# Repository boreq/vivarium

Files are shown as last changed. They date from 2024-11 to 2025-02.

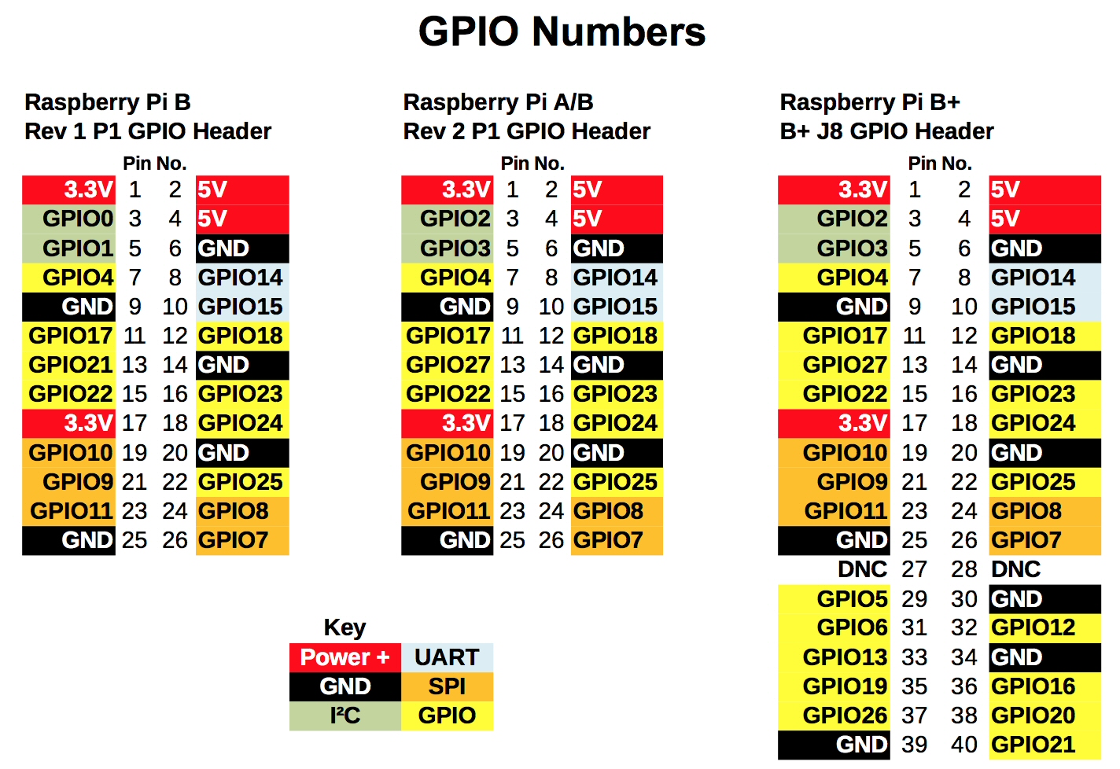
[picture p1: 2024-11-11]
automation/pins.jpg

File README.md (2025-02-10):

# Vivarium

Automation and designs for my vivarium. This readme was written as a desperate
attempt at helping future me when something inevitably breaks at the worst
possible moment.

## Vivarium

### Plants

- [*Pellaea rotundifolia*](https://duckduckgo.com/?q=Pellaea+rotundifolia&iar=images&iax=images&ia=images)
- [*Hemionitis arifolia*](https://duckduckgo.com/?q=Hemionitis+arifolia&iax=images&ia=images)
- [*Nephrolepis cordifolia* ‘Duffii’](https://duckduckgo.com/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)
- [*Pyrrosia nummularifolia*](https://duckduckgo.com/?q=Pyrrosia+nummularifolia&iax=images&ia=images)
- [*Phymatosorus diversifolius*](https://duckduckgo.com/?q=Phymatosorus+diversifolius&iar=images&iax=images&ia=images)
- [*Microgramma nitida*](https://duckduckgo.com/?q=Microgramma+nitida&iar=images&iax=images&ia=images)
- [*Pleurozium schreberi*](https://duckduckgo.com/?q=Pleurozium+schreberi&iax=images&ia=images)
- [*Polytrichum commune*](https://duckduckgo.com/?q=Polytrichum+commune&iax=images&ia=images)
- [*Microsorium pteropus* var. *petite*](https://duckduckgo.com/?q=Microsorium+pteropus+var+petite&iar=images&iax=images&ia=images)
- [*Limnobium laevigatum*](https://duckduckgo.com/?q=Limnobium+laevigatum&iar=images&iax=images&ia=images)
- [*Anubias barteri* var. *nana*](https://duckduckgo.com/?t=ffab&q=Anubias+barteri+var.+nana&iax=images&ia=images)

### Animals

- [*Armadillidium klugii*](https://duckduckgo.com/?hps=1&q=Armadillidium+klugii&iax=images&ia=images)
- [*Caridina multidentata*](https://duckduckgo.com/?hps=1&q=Caridina+multidentata&iax=images&ia=images)
- [*Clithon corona*](https://duckduckgo.com/?hps=1&q=Clithon+corona&iax=images&ia=images)
- [Unspecified species of springtails](https://duckduckgo.com/?q=vivarium++springtails&t=ffab&iar=images&iax=images&ia=images)
- [*Lepidodactylus lugubris*](https://duckduckgo.com/?t=ffab&q=Lepidodactylus+lugubris&iax=images&ia=images)

### DICP (Dynamic Isopod Configuration Protocol) identifiers

- Baltazar
- Brunhilda

### Planting

There is a layer of sphagnum moss + orchid bark + coco coir mixed 1-1-1 at the
bottom of the tank. There is only spaghnum moss in the pots.

### Automation 

See `./automation`, use `kicad`. The schematic doesn't have pulldowns on pins as
it seems to work without them because of reasons.

GPIO pins used for relays are:
- `GPIO 22` = output `3`
- `GPIO 23` = output `4`
- `GPIO 24` = output `2`
- `GPIO 25` = output `1`

GPIO pins used for the water tank sensor are:
- `GPIO 17` = trig
- `GPIO 18` = echo

This is `Raspberry Pi 1 Model B`.

Raspberry Pi OS is
[here](https://www.raspberrypi.com/software/operating-systems/), use lite. It's
debian. Arch Linux ARM doesn't support this Pi out of the box anymore.

The wifi dongle is `TP-Link TL-WN725N` and was chosen without any thought put into it.

The config is in `/etc/network/interfaces`. The manual is
[here](https://wiki.debian.org/NetworkConfiguration). The manual for WIFI is
[here](https://wiki.debian.org/WiFi/HowToUse#Manual).

Wired connection config would look something like this:

```
auto eth0
iface eth0 inet static
	address 192.168.0.30/24
	gateway 192.168.0.1/24
```

WIFI config would look something like this:

```
auto wlan0
allow-hotplug wlan0
iface wlan0 inet dhcp
        wpa-ssid somessid
        wpa-psk somepassword
```

The login info is on the device. SSH isn't running on port 22.

### Terrarium

[RNT-45 from Aqua Nova/Reptile Nova](http://archive.today/2024.11.03-024309/https://www.aqua-nova.pl/?a=produkty&opcja=show&idprod=1800&idkat=55).

### Lid

The material is 5mm thick foamed PVC.

The glue is silicone branded "for aquarium glass" as that's what I had lying
around.

Open `lid.dxf` with `librecad` in case you need to redo a panel.

### Light

Use strong double-sided tape for LED strips, the tape that's on them is never
strong enough.

The power connector is XT60.

#### Strip 1

Those are the parameters for the LED strip supposedly but who knows:

```
Color: 4000-4500K
LEDs per meter: 320
Flux: 900lm/m
Recommended power supply: 10W per meter (lol)
```

Basically the whole thing was used, I just measured the amps to be around 0.85A
which is closer to 2W per meter.

#### Strip 2

```
Color: 4000K
LEDs per meter: 320
```

#### UV

[Repti Planet UVB 5.0
Tropical](https://web.archive.org/web/20250115155401/https://reptiplanet.pet/portfolio-items/repti-planet-repti-uvb-5-0-3/),
running since 2025-01-15.

### False bottom

Use 20 PPI foam, ordering 45 PPI was a fuck up.

### Internal dividers

Don't use the metal mesh for water inlets, its so annoying to work with. Next
time the pump compartment can be slightly smaller I think.

### Waterfall

The pump hose is a 10mm one. 

The waterfall was spraying at the back wall and had to be redone as the water
was leaking. Checking for leaks as early as possible was a really good idea.

## Isopodarium

### Animals

- [*Porcellio scaber* "Dalmatian"](https://duckduckgo.com/?q=Porcellio+scaber+%22Dalmatian%22&iar=images)
- [*Cubaris* sp. "Panda King"](https://duckduckgo.com/?q=Cubaris+sp.+"Panda+King"&iar=images)

### Terrarium

- A riced up [ÅKERBÄR from IKEA](https://archive.is/wgjBQ).

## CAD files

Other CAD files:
lid.dxf

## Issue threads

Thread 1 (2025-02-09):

Screenshots

boreq, 2025-02-09:

boreq, 2025-02-09:
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

boreq, 2025-02-09:
Oh no is the trick with uploading images to issues fixed and everyone gets a private link to media now NOOO I don't wanna put the images in the repo

Closed 2025-02-09.

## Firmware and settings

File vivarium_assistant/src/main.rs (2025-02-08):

#![feature(duration_constructors)]

use anyhow::anyhow;
use env_logger::Env;
use log::{error, info};
use std::sync::{Arc, Mutex};
use std::time::Duration;
use std::{env, fs};
use tokio::time;
use vivarium_assistant::adapters::{self, config, metrics};
use vivarium_assistant::config::Config;
use vivarium_assistant::domain::outputs::{CurrentTimeProvider, OutputStatus};
use vivarium_assistant::domain::sensors::{MedianCache, WaterLevel};
use vivarium_assistant::domain::{self, GPIO};
use vivarium_assistant::domain::{outputs, sensors};
use vivarium_assistant::errors::Result;
use vivarium_assistant::ports::http::{self, Server};

#[cfg(feature = "raspberry_pi")]
use vivarium_assistant::adapters::raspberrypi;

const UPDATE_SENSORS_EVERY: Duration = Duration::from_secs(10);
const UPDATE_OUTPUTS_EVERY: Duration = Duration::from_millis(100);
const WATER_SENSOR_SMOOTHING_PERIOD: Duration = Duration::from_mins(5); // should presumably be
                                                                        // significantly larger
                                                                        // than
                                                                        // UPDATE_SENSORS_EVERY

#[tokio::main]
async fn main() -> Result<()> {
    env_logger::Builder::from_env(Env::default().default_filter_or("info")).init();

    #[cfg(not(feature = "raspberry_pi"))]
    let gpio = adapters::MockGPIO::new();

    #[cfg(feature = "raspberry_pi")]
    let gpio = raspberrypi::GPIO::new()?;

    #[cfg(not(feature = "raspberry_pi"))]
    let i2c = adapters::MockI2C::new();

    #[cfg(feature = "raspberry_pi")]
    let i2c = raspberrypi::I2C::new()?;

    let aht20 = sensors::AHT20::new(i2c)?;

    let current_time_provider = adapters::CurrentTimeProvider::new();
    let mut metrics = metrics::Metrics::new()?;
    metrics.set_startup_time(&current_time_provider.now());

    let config = load_config()?;

    let controller = SafeController::new(outputs::Controller::new(
        config.outputs(),
        gpio.clone(),
        current_time_provider.clone(),
    )?);
    let server = Server::new();

    let mut water_level_sensors = vec![];
    for definition in config.water_level_sensors().sensors() {
        let trig = gpio.output(&definition.trig_pin())?;
        let echo = gpio.input(&definition.echo_pin())?;
        let sensor = sensors::HCSR04::new(trig, echo)?;
        let sensor = sensors::WaterLevelSensor::new(
            definition.min_distance(),
            definition.max_distance(),
            sensor,
        )?;
        water_level_sensors.push(QueriedWaterLevelSensor {
            name: definition.name().clone(),
            sensor,
            cache: MedianCache::new(WATER_SENSOR_SMOOTHING_PERIOD)?,
        });
    }

    setup_failsafe_hook(controller.clone());

    tokio::spawn({
        let metrics = metrics.clone();
        async move { update_water_sensors_loop(water_level_sensors, metrics).await }
    });

    if let Some(aht_20_name) = config.aht_20() {
        tokio::spawn({
            let metrics = metrics.clone();
            let aht_20_name = aht_20_name.clone();
            async move { update_aht20_loop(&aht_20_name, aht20, metrics).await }
        });
    }

    tokio::spawn({
        let metrics = metrics.clone();
        let controller = controller.clone();
        async move { server_loop(&server, &config, metrics, controller).await }
    });
    update_outputs_loop(controller, metrics.clone()).await;
    Ok(())
}

fn setup_failsafe_hook<C>(controller: C)
where
    C: Controller + 'static,
{
    std::panic::set_hook(Box::new({
        let default_panic = std::panic::take_hook();
        move |info| {
            controller.fail_safe();
            default_panic(info);
        }
    }));
}

fn load_config() -> Result<Config> {
    let args: Vec<String> = env::args().collect();
    if args.len() != 2 {
        return Err(anyhow!("usage: program path_to_config_file.toml"));
    }

    let config_string = fs::read_to_string(args.get(1).unwrap())?;
    config::load(&config_string)
}

async fn server_loop<M, C>(server: &Server, config: &Config, metrics: M, controller: C)
where
    M: http::Metrics + Sync + Send + Clone + 'static,
    C: http::Controller + Sync + Send + Clone + 'static,
{
    let deps = http::Deps::new(metrics, controller);

    loop {
        match server.run(config, deps.clone()).await {
            Ok(_) => {
                error!("for some reason the server exited without returning any errors?")
            }
            Err(err) => {
                error!("the server exited with an error: {err}")
            }
        }
    }
}

async fn update_water_sensors_loop<T, M>(
    mut sensors: Vec<QueriedWaterLevelSensor<T>>,
    mut metrics: M,
) where
    T: sensors::DistanceSensor,
    M: Metrics,
{
    let zero = sensors::WaterLevel::new(0.0).unwrap();

    loop {
        for sensor in &mut sensors {
            match sensor.sensor.measure() {
                Ok(value) => {
                    info!(
                        "Water level sensor '{name}' reported water level '{level}'",
                        name = sensor.name,
                        level = value
                    );
                    sensor.cache.put(value);
                }
                Err(err) => {
                    error!(
                        "Water level sensor '{name}' returned an error: {err}",
                        name = sensor.name,
                        err = err
                    );
                }
            };

            let level = match sensor.cache.get() {
                Some(value) => value,
                None => &zero,
            };
            metrics.report_water_level(&sensor.name, level);
        }
        time::sleep(UPDATE_SENSORS_EVERY).await;
    }
}

async fn update_aht20_loop<M, I>(
    sensor_name: &sensors::SensorName,
    mut sensor: sensors::AHT20<I>,
    mut metrics: M,
) where
    M: Metrics,
    I: domain::I2C,
{
    let zero_temperature = sensors::Temperature::new(0.0).unwrap();
    let zero_humidity = sensors::Humidity::new(0.0).unwrap();

    loop {
        match sensor.measure() {
            Ok(value) => {
                info!(
                        "AHT20 sensor '{name}' reported temperature '{temperature}' and humidity '{humidity}'",
                        name = sensor_name,
                        temperature = value.temperature(),
                        humidity = value.humidity(),
                    );
                metrics.report_temperature(sensor_name, &value.temperature());
                metrics.report_humidity(sensor_name, &value.humidity());
            }
            Err(err) => {
                error!(
                    "AHT20 sensor '{name}' returned an error: {err}",
                    name = sensor_name,
                    err = err
                );
                metrics.report_temperature(sensor_name, &zero_temperature);
                metrics.report_humidity(sensor_name, &zero_humidity);
            }
        };

        time::sleep(UPDATE_SENSORS_EVERY).await;
    }
}

async fn update_outputs_loop<C, M>(controller: C, mut metrics: M)
where
    C: Controller,
    M: Metrics,
{
    loop {
        controller.update_outputs();
        for entry in controller.status() {
            metrics.report_output(&entry.name, &entry.state);
        }
        time::sleep(UPDATE_OUTPUTS_EVERY).await;
    }
}

struct QueriedWaterLevelSensor<T: sensors::DistanceSensor> {
    name: sensors::SensorName,
    sensor: sensors::WaterLevelSensor<T>,
    cache: sensors::MedianCache<WaterLevel>,
}

trait Metrics {
    fn report_output(&mut self, output: &outputs::OutputName, state: &outputs::OutputState);
    fn report_water_level(&mut self, sensor: &sensors::SensorName, level: &sensors::WaterLevel);
    fn report_temperature(
        &mut self,
        sensor: &sensors::SensorName,
        temperature: &sensors::Temperature,
    );
    fn report_humidity(&mut self, sensor: &sensors::SensorName, humidity: &sensors::Humidity);
}

impl Metrics for metrics::Metrics {
    fn report_output(&mut self, output: &outputs::OutputName, state: &outputs::OutputState) {
        metrics::Metrics::report_output(self, output, state);
    }

    fn report_water_level(&mut self, sensor: &sensors::SensorName, level: &sensors::WaterLevel) {
        metrics::Metrics::report_water_level(self, sensor, level);
    }

    fn report_temperature(
        &mut self,
        sensor: &sensors::SensorName,
        temperature: &sensors::Temperature,
    ) {
        metrics::Metrics::report_temperature(self, sensor, temperature);
    }

    fn report_humidity(&mut self, sensor: &sensors::SensorName, humidity: &sensors::Humidity) {
        metrics::Metrics::report_humidity(self, sensor, humidity);
    }
}

trait Controller: Send + Sync {
    fn update_outputs(&self);
    fn status(&self) -> Vec<OutputStatus>;
    fn fail_safe(&self);
}

trait WrappedController: Send {
    fn update_outputs(&mut self);
    fn status(&mut self) -> Vec<OutputStatus>;
    fn clear_overrides(&mut self, output_name: outputs::OutputName) -> Result<()>;
    fn add_override(
        &mut self,
        output_name: outputs::OutputName,
        state: outputs::OutputState,
        activation: outputs::ScheduledActivation,
    ) -> Result<()>;
    fn fail_safe(&mut self);
}

impl<OP, CTP> WrappedController for outputs::Controller<OP, CTP>
where
    OP: domain::OutputPin + Send,
    CTP: outputs::CurrentTimeProvider + Send,
{
    fn update_outputs(&mut self) {
        outputs::Controller::update_outputs(self);
    }

    fn status(&mut self) -> Vec<OutputStatus> {
        outputs::Controller::status(self)
    }

    fn clear_overrides(&mut self, output_name: outputs::OutputName) -> Result<()> {
        outputs::Controller::clear_overrides(self, output_name)
    }

    fn fail_safe(&mut self) {
        outputs::Controller::fail_safe(self)
    }

    fn add_override(
        &mut self,
        output_name: outputs::OutputName,
        state: outputs::OutputState,
        activation: outputs::ScheduledActivation,
    ) -> Result<()> {
        outputs::Controller::add_override(self, output_name, state, activation)
    }
}

struct SafeController<T>
where
    T: WrappedController,
{
    controller: Arc<Mutex<T>>,
}

impl<T> SafeController<T>
where
    T: WrappedController,
{
    fn new(controller: T) -> Self {
        Self {
            controller: Arc::new(Mutex::new(controller)),
        }
    }
}

impl<T> Controller for SafeController<T>
where
    T: WrappedController,
{
    fn update_outputs(&self) {
        let mut controller = self.controller.lock().unwrap();
        (*controller).update_outputs();
    }

    fn status(&self) -> Vec<OutputStatus> {
        let mut controller = self.controller.lock().unwrap();
        (*controller).status()
    }

    fn fail_safe(&self) {
        let mut controller = self.controller.lock().unwrap();
        (*controller).fail_safe()
    }
}

impl<T> http::Controller for SafeController<T>
where
    T: WrappedController,
{
    fn clear_overrides(&mut self, output_name: outputs::OutputName) -> Result<()> {
        let mut controller = self.controller.lock().unwrap();
        (*controller).clear_overrides(output_name)
    }

    fn add_override(
        &mut self,
        output_name: outputs::OutputName,
        state: outputs::OutputState,
        activation: outputs::ScheduledActivation,
    ) -> Result<()> {
        let mut controller = self.controller.lock().unwrap();
        (*controller).add_override(output_name, state, activation)
    }
}

impl<T> Clone for SafeController<T>
where
    T: WrappedController,
{
    fn clone(&self) -> Self {
        Self {
            controller: self.controller.clone(),
        }
    }
}

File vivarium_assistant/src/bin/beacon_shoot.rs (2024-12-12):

use std::thread;
use std::time::Duration;
use vivarium_assistant::domain::OutputPin;
use vivarium_assistant::{
    adapters::raspberrypi,
    domain::{PinNumber, GPIO},
    errors::Result,
};

fn main() -> Result<()> {
    let gpio = raspberrypi::GPIO::new()?;

    let mut pin_light = gpio.output(&PinNumber::new(25)?)?;
    let mut pin_misting = gpio.output(&PinNumber::new(24)?)?;
    let mut pin_beacon = gpio.output(&PinNumber::new(22)?)?;

    pin_light.set_high();

    thread::sleep(Duration::from_secs(5));

    pin_beacon.set_high();

    thread::sleep(Duration::from_secs(5));

    pin_misting.set_high();

    thread::sleep(Duration::from_secs(5));

    pin_beacon.set_low();
    pin_misting.set_low();

    Ok(())
}

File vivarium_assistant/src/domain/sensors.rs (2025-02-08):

use std::{fmt::Display, thread, time::Duration};

use crate::errors::Result;
use anyhow::anyhow;
use chrono::{TimeDelta, Utc};

use super::{InputPin, OutputPin, PinNumber, I2C};

#[derive(Debug, Clone, Copy, PartialEq, PartialOrd)]
pub struct Humidity {
    percentage: f32,
}

impl Humidity {
    pub fn new(percentage: f32) -> Result<Self> {
        if !percentage.is_finite() {
            return Err(anyhow!("WHY CAN'T YOU JUST BE NORMAL?!"));
        }

        if percentage < 0.0 {
            return Err(anyhow!("percentage can't be negative"));
        }

        if percentage > 1.0 {
            return Err(anyhow!("percentage can't be above 100"));
        }

        Ok(Self { percentage })
    }

    pub fn percentage(&self) -> f32 {
        self.percentage
    }
}

impl Display for Humidity {
    fn fmt(&self, f: &mut std::fmt::Formatter<'_>) -> std::fmt::Result {
        write!(f, "{:.0}%", self.percentage * 100.0)
    }
}

#[derive(Debug, Clone, Copy, PartialEq, PartialOrd)]
pub struct Temperature {
    celcius: f32,
}

impl Temperature {
    pub fn new(celcius: f32) -> Result<Self> {
        if !celcius.is_finite() {
            return Err(anyhow!("WHY CAN'T YOU JUST BE NORMAL?!"));
        }

        if celcius < 0.0 {
            return Err(anyhow!("impossible value: time to worry 🥶"));
        }

        if celcius > 100.0 {
            return Err(anyhow!("impossible value: time to worry 🥵"));
        }

        Ok(Self { celcius })
    }

    pub fn celcius(&self) -> f32 {
        self.celcius
    }
}

impl Display for Temperature {
    fn fmt(&self, f: &mut std::fmt::Formatter<'_>) -> std::fmt::Result {
        write!(f, "{:.1}C", self.celcius)
    }
}

#[derive(Debug, Clone, Copy, PartialEq, PartialOrd)]
pub struct Distance {
    meters: f32,
}

impl Distance {
    pub fn new(meters: f32) -> Result<Self> {
        if !meters.is_finite() {
            return Err(anyhow!("WHY CAN'T YOU JUST BE NORMAL?!"));
        }

        if meters < 0.0 {
            return Err(anyhow!("distance can't be negative"));
        }

        if meters > 5.0 {
            return Err(anyhow!("impossible value: too large"));
        }

        Ok(Self { meters })
    }

    pub fn meters(&self) -> f32 {
        self.meters
    }
}

#[derive(Debug, Clone, Copy, PartialEq)]
pub struct WaterLevel {
    percentage: f32,
}

impl WaterLevel {
    pub fn new(percentage: f32) -> Result<Self> {
        if !percentage.is_finite() {
            return Err(anyhow!("WHY CAN'T YOU JUST BE NORMAL?!"));
        }

        if percentage < 0.0 {
            return Err(anyhow!("percentage can't be negative"));
        }

        Ok(Self { percentage })
    }

    pub fn percentage(&self) -> f32 {
        self.percentage
    }
}

impl PartialOrd for WaterLevel {
    fn partial_cmp(&self, other: &Self) -> Option<std::cmp::Ordering> {
        Some(self.cmp(other))
    }
}

impl Eq for WaterLevel {}

impl Ord for WaterLevel {
    fn cmp(&self, other: &Self) -> std::cmp::Ordering {
        // the constructor verifies that percentage is_finite so I understand this can't fail
        self.percentage.partial_cmp(&other.percentage()).unwrap()
    }
}

impl Display for WaterLevel {
    fn fmt(&self, f: &mut std::fmt::Formatter<'_>) -> std::fmt::Result {
        write!(f, "{:.0}%", self.percentage * 100.0)
    }
}

#[derive(Debug, Clone, PartialEq)]
pub struct SensorName {
    name: String,
}

impl SensorName {
    pub fn new(name: impl Into<String>) -> Result<Self> {
        let name = name.into();
        if name.is_empty() {
            return Err(anyhow!("sensor name can't be empty"));
        }
        Ok(Self { name })
    }

    pub fn name(&self) -> &str {
        &self.name
    }
}

impl Display for SensorName {
    fn fmt(&self, f: &mut std::fmt::Formatter<'_>) -> std::fmt::Result {
        write!(f, "{}", self.name)
    }
}

#[derive(Debug, Clone, PartialEq)]
pub struct WaterLevelSensorDefinition {
    name: SensorName,
    echo_pin: PinNumber,
    trig_pin: PinNumber,
    min_distance: Distance,
    max_distance: Distance,
}

impl WaterLevelSensorDefinition {
    pub fn new(
        name: SensorName,
        echo_pin: PinNumber,
        trig_pin: PinNumber,
        min_distance: Distance,
        max_distance: Distance,
    ) -> Result<Self> {
        if echo_pin == trig_pin {
            return Err(anyhow!("pins must be different"));
        }

        if min_distance <= max_distance {
            return Err(anyhow!(
                "min water level distance must be larger than max water level distance"
            ));
        }

        Ok(Self {
            name,
            echo_pin,
            trig_pin,
            min_distance,
            max_distance,
        })
    }

    pub fn name(&self) -> &SensorName {
        &self.name
    }

    pub fn echo_pin(&self) -> PinNumber {
        self.echo_pin
    }

    pub fn trig_pin(&self) -> PinNumber {
        self.trig_pin
    }

    pub fn min_distance(&self) -> Distance {
        self.min_distance
    }

    pub fn max_distance(&self) -> Distance {
        self.max_distance
    }
}

#[derive(Debug, Clone, PartialEq)]
pub struct WaterLevelSensorDefinitions {
    sensors: Vec<WaterLevelSensorDefinition>,
}

impl WaterLevelSensorDefinitions {
    pub fn new(sensors: &[WaterLevelSensorDefinition]) -> Result<Self> {
        let mut v = vec![];
        for (i, a) in sensors.iter().enumerate() {
            for (j, b) in sensors.iter().enumerate() {
                if i == j {
                    continue;
                }

                if a.name == b.name {
                    return Err(anyhow!("identical sensors names"));
                }

                if a.echo_pin == b.echo_pin
                    || a.echo_pin == b.trig_pin
                    || a.trig_pin == b.echo_pin
                    || a.trig_pin == b.trig_pin
                {
                    return Err(anyhow!("duplicate pin numbers"));
                }
            }
            v.push(a.clone());
        }

        Ok(Self { sensors: v })
    }

    pub fn sensors(&self) -> &[WaterLevelSensorDefinition] {
        &self.sensors
    }
}

pub trait DistanceSensor {
    fn measure(&mut self) -> Result<Distance>;
}

pub struct WaterLevelSensor<S: DistanceSensor> {
    min_distance: Distance,
    max_distance: Distance,
    distance_sensor: S,
}
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

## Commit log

2024-11-05 Add lid
    [lid.dxf]
2024-11-11 Add schematics for automation
    [automation.kicad_pcb, automation.kicad_sch]
2024-11-11 Document pin mappings
2024-11-15 LED strips are coming off
2024-11-22 Add some domain objects for sensor values
2024-11-29 Update the relay circuit and add the distance sensor
    [automation.kicad_sch]
2024-11-29 Add sensor types
2024-11-29 Load water level sensors config
2024-11-30 Update pin numbers
2024-11-30 Add water level sensors to metrics
2024-12-01 Remove a debug println
2024-12-01 Enable cross compiling for raspberry pi
2024-12-01 Fix async functions using normal sleep, don't hold the mutex when sleeping
    [main.rs]
2024-12-02 Fix incorrect output pin state being reported on rpi
    [raspberrypi.rs]
2024-12-02 Fix incorrect mapping of pin levels to output states
    [outputs.rs]
2024-12-04 Add springtails
2024-12-05 Rework the way deps are passed to the server
    I've no idea what I'm doing this is probably the most complicated way
    ever.
    [http.rs, main.rs]
2024-12-06 Update output state every 100ms
    Updating every 1s means that you can make a mistake of ~33% when running
    something that takes 3s if the stars don't allign well.
    [main.rs]
2024-12-07 Fix using incorrect NaiveTime
    I'm under the impression that we were using incorrect local time. Added
    a function to force using the correct one by making it impossible to
    pass a wrong datetime to it.
    [outputs.rs]
2024-12-16 Add HTP
    [automation.kicad_sch]
2024-12-16 Correct cable colors
    [automation.kicad_sch]
2024-12-16 Add humidity and temperature
2024-12-17 Smoothen the water level measurements
    I'm so tired that I'm questioning whether smoothen is a real word but I
    think it is.
2025-01-23 Fix 'always on' inputs never being turned on
    [outputs.rs]
2025-01-24 Make it possible to run the program without a raspberry pi
2025-01-25 Fix a raspberry pi build
    [main.rs, raspberrypi.rs]
2025-01-26 Change the error message or I will get very angry at myself in the future
    [outputs.rs]
